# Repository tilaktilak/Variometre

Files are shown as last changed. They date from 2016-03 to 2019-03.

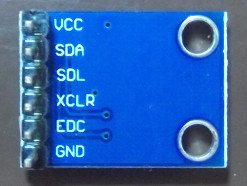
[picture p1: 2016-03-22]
schematic/BMP085.jpg

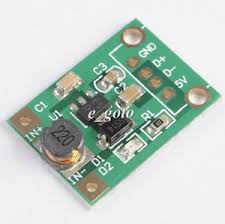
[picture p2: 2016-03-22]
schematic/charger.jpeg

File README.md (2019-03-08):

# Variometre

Here the first Paragliding Computer I've designed : 

(https://postimg.cc/18d83vHh)

This is a variometer / gps / sd logger Atmega328p based project : 

Components :
* a SD card reader connected through SPI to the arduino
* a Nokia LCD screen connected to SPI
* a BMP180 (pressure sensor) connected through I2C
* a GPS Neo-6M receiver in UART.

The PCB is powerd by a 1s battery + a USB battery charger and a boost module to generate 5V.

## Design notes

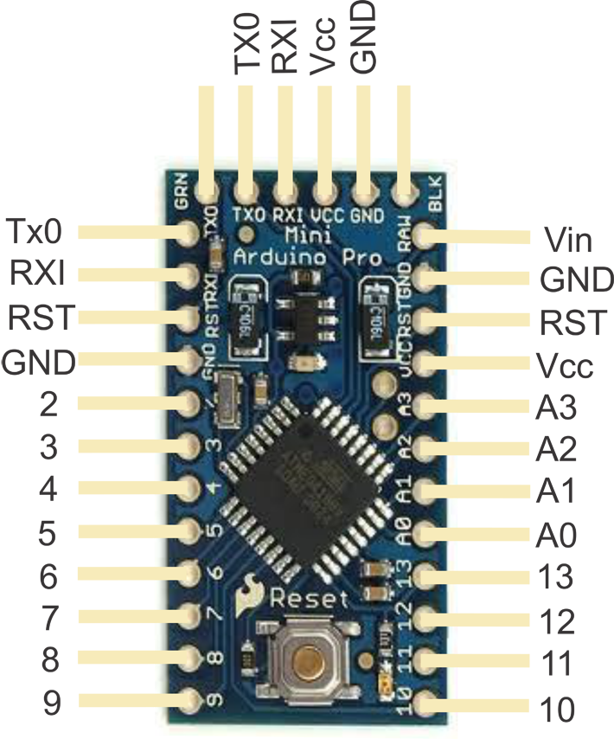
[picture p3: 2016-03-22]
schematic/arduino.png

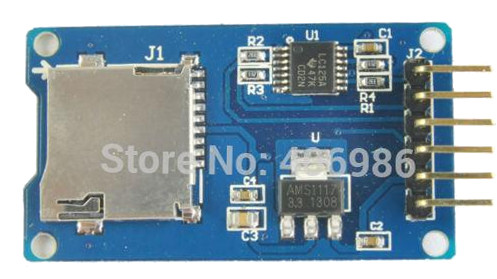
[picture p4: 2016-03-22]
schematic/sd_readet.jpg

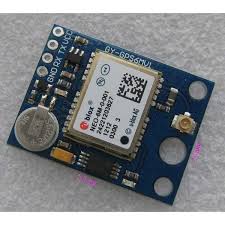
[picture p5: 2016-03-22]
schematic/gps.jpeg

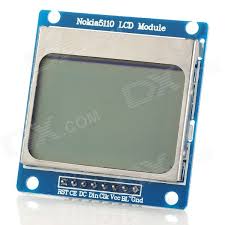
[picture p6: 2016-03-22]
schematic/nokia.jpeg

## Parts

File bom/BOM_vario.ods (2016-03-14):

 |  |  | CAHIER DES CHARGES BOITIER | FEATURES
NOKIA LCD (http://www.ebay.fr/itm/84-48-84x84-LCD-Module-White-backlight-adapter-PCB-for-Nokia-5110-Arduino-MM-/331555581551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) | 1.85 |  | LED CHARGEUR VISIBLE | INTER EXTINCTION SOFTWARE (Ferme fichier SD)
BMP085 (http://www.ebay.fr/itm/BMP180-Replace-BMP085-Digital-Barometric-Pressure-Sensor-Board-Module-NEW-/201539355190) | 1.12 |  | CARTE SD ACCESSIBLE | Clavier : changer les seuils de beep
GPS (http://www.ebay.fr/itm/1p-Ublox-NEO-6M-V2-Flight-GPS-Module-Controleur-De-Vol-pour-Arduino-MWC-IMU-APM2-/161887869415) | 10 |  | INTER ACCESSIBLE MAIS PAS TROP | Clavier : Afficher les stats du vol
SD reader (http://www.ebay.fr/itm/Micro-Storage-Board-Mciro-for-SD-TF-Card-Memory-Shield-Module-SPI-For-Arduino-JK-/262241628919) | 1 |  | USB PRISE ACCESSIBLE | Clavier : Afficher la position courante (en cas de vache !)
DCDC boost (http://www.ebay.fr/itm/221913300409) | 1 |  | BUZZER DEVANT DES TROUS | Mise en veille si pas de chg de position pdt 5mins (Puis réveil)
USB charger (http://www.ebay.fr/itm/5V-Micro-USB-1A-18650-Lithium-Battery-Charging-Board-Charger-Module-New-FR-/111777518426) | 1 |  | ANTENNE GPS NON COUVERTE
1S battery (http://www.ebay.fr/itm/3-7V-1000MAH-1200mAh-25C-Lipo-Battery-RC-Walkera-WKLIPO-5-10-5G4Q3-SYMA-S006-H-/262214846844) | 2.3 |  | CONNECTEUR FLASH ACCESSIBLE
Arduino (http://www.ebay.com/itm/Pro-Mini-atmega328-Board-5V-16M-Arduino-Compatible-Nano-top-/181947224345) | 1.45
INTER ON OFF (http://www.ebay.com/itm/20Pcs-SS12D00G3-2-Position-SPDT-1P2T-3-Pin-PCB-Panel-Vertical-Slide-Switch-FG-/272105930058) | 0.75
SWITCH CLAVIER (http://www.ebay.com/itm/50PCS-6x6x6-mm-Miniature-Micro-Momentary-Tactile-Tact-Touch-Push-Button-Switch-/262136738351) | 0.98
Boitier x 5 (OPTION) |  | 3.73
TOTAL | 21.45

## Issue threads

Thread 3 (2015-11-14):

Mauvaise Ecriture d'Altitude dans IGC (Pressure+GPS)

tilaktilak, 2015-11-14:
Check dtostrf cheat
GPS Alt : Ajouter des zeros lorsque non rempli

tilaktilak, 2015-12-28:
Erreur sur des paquets incomplets : Il faut d'abord remplir un buffer (200 char si possible) et ensuite le sonder pour parser)

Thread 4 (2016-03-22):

Fix GPS lent

tilaktilak, 2016-03-22:
Surement dû au fait que les valeurs sont filtrées si non cohérentes en entrée. Il faut que le voyant indiquant GPS OK soit cohérent avec le début de l'écriture des lignes dans la SD.
Tenter d'améliorer le fix GPS / Gérer le nombre de points par secondes

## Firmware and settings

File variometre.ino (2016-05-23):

#include<stdlib.h>
#include <avr/sleep.h>
#include <SPI.h>
#include <Wire.h>
#include <Adafruit_BMP085.h>
#include <SdFat.h>
#include <PCD8544.h>
#include <EEPROM.h>
#include <TinyGPS++.h>
TinyGPSPlus gps;
#define SIZE_MEM  13

#define     CHANGE_LEVEL    1
#define     ENTER           2
#define     EXIT            3

#define PLOT
//#define NO_TONE

typedef union __attribute__((__packed__)){
    struct __attribute__((__packed__)){
        uint8_t index;
        float   alt_max;
        float   rate_max;
        uint32_t minutes;
    };
    byte raw[sizeof(uint8_t)+2*sizeof(float)+sizeof(uint32_t)];

}memory_t;

memory_t mem;

// Software SPI (slower updates, more flexible pin options):
// pin 7 - Serial clock out (SCLK)
// pin 6 - Serial data out (DIN)
// pin 5 - Data/Command select (D/C)
// pin 4 - LCD chip select (CS)
// pin 3 - LCD reset (RST)

static PCD8544 lcd;

static Adafruit_BMP085 bmp;

SdFat sd;
SdFile dataFile;
char filename[9] = "vari.igc";

// ADD of mem struct in EEPROM
#define STAT_GLOBAL 0x00

void read_EEPROM(byte offset) {
    for (uint8_t i = offset; i < SIZE_MEM; i++){
        mem.raw[i] = EEPROM.read(i);
        Serial.print(mem.raw[i]);
    }
}

void write_EEPROM(byte offset) {
    for (uint8_t i = offset; i < SIZE_MEM;i++){
        EEPROM.write(i,mem.raw[i]);
    }
}

typedef union __attribute__((__packed__)){
    struct __attribute__((__packed__)){
        char b ;
        char time[6];
        char lat[8];
        char lng[9];
        char a;
        char pAlt[5];
        char gAlt[5];
    };
    char raw[35];
}igc_t;

igc_t cur_igc;

char is_gps_valid = 'E';
#if 0
typedef struct{
    const char text[10];
    char value;
    void (* funct)();
}t_item;

typedef struct{
    const char title[15];
    t_item items[2];
    char index;
}t_page;

float level = 0.0;
void set_level(char value){
    level = (float)value;
}

void screen_stat(void){
    lcd.print("stats");
}
t_page page[2] = {"MENU PRINCIPAL",{"[-Level-] ",0x02,set_level},{"[-Stats-] ",0x00,screen_stat},0x00};

#define l_page 0
#define l_item 1
#define l_value 2
void do_menu(){
    t_page cur_page = page[0]; // Page to screen
    char button = 0x00;
    uint8_t i = 0;
    char level; // 0, 1 or 2
    bool exit_menu = false;
    while(!exit_menu){
        //display(page,level); // page with highlight level
        switch(0){//Read_button()){
            case CHANGE_LEVEL :
                if(level < 0X02) level ++;
                else level = 0x00;
                break;
            case ENTER :
                if(level == l_page){cur_page=page[++i];}
                if(level == l_item){cur_page = index++;}
                if(level == l_value){cur_page.item[cur_page.index].funct();}
                break;
            case EXIT :
                exit_menu = true;
                break;
            case Default:
                break;
        }
        }
    }
#endif
    static float batt;
    void setup() {
        memset(&cur_igc,'0',sizeof(cur_igc));
        cur_igc.a = 'A';
        cur_igc.b = 'B';

        // Fetch last file index
        mem.index = 0;
        mem.alt_max = 0.0f;
        mem.rate_max = 0.0f;
        mem.minutes = 0;
        // Fetch stats in memory
        Serial.begin(9600);

        read_EEPROM(STAT_GLOBAL);
        Serial.println(mem.alt_max);
        // Prepare filename with current index
        filename[1] = (mem.index / 100) % 10 + '0';
        filename[2] = (mem.index / 10) % 10 + '0';
        filename[3] = (mem.index) % 10 + '0';
        mem.index ++;

        lcd.begin(84, 48);
        lcd.clear();

        pinMode(A0, OUTPUT);// Backlight
        pinMode(2, OUTPUT);// Tone
        pinMode(A1, OUTPUT);// Voltage
        digitalWrite(A0,0);


        if (!sd.begin(10, SPI_FULL_SPEED)) {
            sd.initErrorHalt();
        }
        if (!bmp.begin(3)) {
            while (1) {}
        }
        if(!dataFile.open(filename,O_RDWR | O_CREAT | O_TRUNC)){
            lcd.print(F("FILE ERR"));
            lcd.setCursor(0, 5);
            lcd.print(filename);
            while (1);
        }
        
        dataFile.print(F("AXXX Tilak_Logger\r\
HFDTE020911\r\
HFFXA035\r\
HFPLTPILOTINCHARGE: Pierre-Louis TILAK\r\
HFCM2CREW2: not recorded\r\
HFGTYGLIDERTYPE:Advance Alpha5 23\r\
HFGIDGLIDERID:0\r\
HFDTM100GPSDATUM: WGS-1984\r\
HFRFWFIRMWAREVERSION: 1.2\r\
HFRHWHARDWAREVERSION: 2016\r\
HFFTYFRTYPE: Ardiuno Tilak Logger\r\
HFGPSGPS:Ublox Neo6m\r\
HFPRSPRESSALTSENSOR: BMP180\r\
HFCIDCOMPETITIONID:\r\
HFCCLCOMPETITIONCLASS:\r"));
        // Flush data
        dataFile.sync();
        dataFile.getWriteError();

        // Initialize battery voltage measure
        batt += (float)analogRead(A1) * (5.0/1023.0) - 0.24;
    }

    uint8_t count;
    bool tone_done = false;
    static int start_beep;
    static int duration, old_duration;
    static int timer;
    static bool inits = true;
    static bool in_flight = true;
    uint8_t i_t = 0;

    void loop() {

        static unsigned long sec = 0;
        static uint8_t old_minu = 0;
        static uint8_t minu = 0;
        static uint8_t hour = 23;
        static unsigned long usec = 0;
        static unsigned long old_usec = 0;
        static float alt, old_alt, smooth;
        static float raw_deriv,derivative;
        static int16_t freq;
        static uint8_t count_lcd = 0;
        static uint8_t count_sd = 0;
        static uint8_t count_gps = 0;
        static float avg_batt;
        static uint8_t avg_batt_count = 0;
        static float ground_speed = 0.0f;

        char heure[8];
#if 0
        if(digitalRead(ENTER)==HIGH){
            delay(1);
            while(digitalRead(ENTER)==HIGH);
            do_menu();
        }
#endif
        // Update Time
        usec = millis();
        sec = usec / 1000;
        minu = sec / 60;
        hour = minu / 60;

        alt = bmp.readAltitude();
        if (inits) {
            smooth = alt;
            old_alt = alt;
            old_usec = usec;
            inits = false;
        }

        // Process Pressure
        smooth = 0.97 * smooth + 0.03* alt;

        // Process Derivative
        if ((old_usec - usec) >= 100) {
            raw_deriv = ((smooth    - old_alt) * 1000) /(usec - old_usec);
            old_usec = usec;
            old_alt = smooth;
        }
        derivative = 0.9 * derivative + 0.1 * raw_deriv;

        //if(abs(derivative) > 1.0){in_flight = true;}
#ifdef PLOT
        dataFile.print(usec);
        dataFile.print(",");
        dataFile.print(smooth);
        dataFile.print(",");
        dataFile.print(derivative);
        dataFile.print(",");
        dataFile.print(raw_deriv);
        dataFile.print("\n");
        if(in_flight){
            // Update stat
            if(mem.rate_max < derivative) mem.rate_max = derivative;
            // Update stat
            if(mem.alt_max < alt) mem.alt_max = alt;
        }
        // Flush data
        dataFile.sync();
        dataFile.getWriteError();
#endif

        // TONE
#define RISING_LEVEL 0.23
#define FALLING_LEVEL 0.4
#define PERIOD_MAX 400
        if (derivative >= RISING_LEVEL) {
            //duration = (int) 50 + 70 / abs(derivative);
            duration = (int) ((-derivative)*70 + 400);
        }
        else if(derivative <= -FALLING_LEVEL){
            //duration = (int) 100 + 200 / abs(derivative);
            duration = (int) ((derivative)*35 +  400);
        }
        else {
            duration = 0;
        }
        duration = constrain(duration, 0, 400);
        freq = (int) (640 + 200 * derivative);
        if(derivative<0)freq-=250;
        freq = constrain(freq, 40, 4000);

        if (!tone_done) {
            if (duration != 0)
#ifndef NO_TONE
                tone(2, freq, duration);
#endif
            tone_done = true;
            start_beep = millis();
            old_duration = duration;
        }
        timer = start_beep + 2 * old_duration - millis();
        if (timer < 10) {
            tone_done = false;
        }
        switch (count) {
            case 1 : // Print data on screen
                count_lcd ++;
                if (count_lcd == 5) {


                    lcd.setCursor(0, 0);

                    if ((hour % 24) < 10) lcd.print("0");
                    lcd.print(hour % 24);
                    lcd.print(":");
                    if ((minu % 60) < 10) lcd.print("0");
                    lcd.print(minu % 60);
                    lcd.print(":");
                    if ((sec % 60) < 10) lcd.print("0");
                    lcd.print(sec % 60);
                    lcd.setCursor(55, 0);

                    avg_batt += (float)analogRead(A1) * (5.0/1023.0) - 0.24;
                    avg_batt_count ++;
                    if(avg_batt_count >= 30){
                        avg_batt /= avg_batt_count;

                        batt = avg_batt;

                        avg_batt = 0;
                        avg_batt_count = 0;

                    }
                    if(batt >= 4.00) lcd.print("~~~}");
                    else if(batt >= 3.80) lcd.print(" ~~}");
                    else if(batt >= 3.70) lcd.print("  ~}");
                    else if(batt >= 3.40) lcd.print("   }");
                    else if(batt >= 1.00){
                        // Got into sleep mode
                        lcd.print(batt);
                        lcd.setCursor(0,3);
                        lcd.print(" BATT LOW !");
                        lcd.setCursor(0,5);
                        lcd.print(" SHUT DOWN !");
                        while(1){
                            tone(2, 500, 1000);
                            delay(3000);
                        }
                        //dataFile.close();
                        lcd.clear();
                        set_sleep_mode(SLEEP_MODE_PWR_DOWN);
                        cli();
                        sleep_enable();
                        sleep_bod_disable();
                        sei();
                        sleep_mode();
                    }
                    else{
                        lcd.setCursor(0,2);
                        lcd.print("Device");
                        lcd.setCursor(0,3);
                        lcd.print("Connected");
                        while(1);
                    }
                    lcd.setCursor(79, 0);

                    lcd.print((gps.location.isValid())?"{":"X");

                    lcd.setCursor(0, 1);
                    lcd.set_size(0x02);
                    lcd.print(ground_speed);

                    lcd.set_size(0x01);
                    lcd.print("km/h  ");
                    lcd.setCursor(0,3);
                    lcd.print(smooth);
                    lcd.print(" m    ");

                    lcd.set_size(0x02);
                    lcd.setCursor(0,4); 
                    if(derivative>0.0){lcd.print("+");}
                    lcd.print(derivative);
                    lcd.set_size(0x01);
                    lcd.print("m/s");
                    count_lcd = 0;
                }
                break;
            case 2: // Read GPS & Write data to SD Card
                //count_sd ++;
                if (in_flight  && gps.location.isValid()) {
                    if((strlen(gps.c_lon)==8)&&
                            (strlen(gps.c_lat)==7)&&
                            (gps.dir_lat=='N'||gps.dir_lat=='S')&&
                            (gps.dir_lon=='W'||gps.dir_lon=='E')&&
                            !(gps.time.hour()==0&&gps.time.minute()==0&&gps.time.second()==0)){
                        ground_speed = gps.speed.kmph();

                        dataFile.print("B");
                        if (gps.time.hour() < 10) dataFile.print(F("0"));
                        dataFile.print(gps.time.hour());

                        if (gps.time.minute() < 10) dataFile.print(F("0"));
                        dataFile.print(gps.time.minute());
                        if (gps.time.second() < 10) dataFile.print(F("0"));
                        dataFile.print(gps.time.second());

                        dataFile.print(gps.c_lat);
                        dataFile.print(gps.dir_lat);
                        dataFile.print(gps.c_lon);
                        dataFile.print(gps.dir_lon);
                        dataFile.print("A");
                        if(smooth<10)dataFile.print("0000");
                        else if(smooth<100) dataFile.print("000");
                        else if(smooth<1000) dataFile.print("00");
                        else if(smooth<10000) dataFile.print("0");
                        dataFile.print(smooth,0);

                        if(smooth<10)dataFile.print("0000");
                        else if(smooth<100) dataFile.print("000");
                        else if(smooth<1000) dataFile.print("00");
                        else if(smooth<10000) dataFile.print("0");
                        dataFile.println(gps.altitude.meters(),0);
                        // Flush data
                        dataFile.sync();
                        dataFile.getWriteError();
                    }
                    count_sd = 0;
                }
                break;
            case 3 :
                if(in_flight){
                    if(minu >= old_minu+10){
                        mem.minutes+= (minu-old_minu);
                        old_minu = minu;
                    }
                    write_EEPROM(STAT_GLOBAL);
                }
                count = 0;
                break;
           default:
                break;
        }
        count++;
    }
    
void serialEvent(){
    while (Serial.available() > 0) {
        gps.encode(Serial.read());
    }
}

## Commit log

2015-10-11 Premier Commit, code example threadé
2015-10-20 version avec beeper,SD et écran - pas de menu ni GPS
2015-10-25 Ralenti du LCD et de la SD
2015-10-25 Version avec GPS + Format correct IGC + MaJ du nom de fichier 0-255
    [variometre.ino]
2015-10-26 Version buggué sur l'affichage - TODO : Essayer d'agrandir/modifier l'affichage, Calibrer l'altitude avec un zero fait grace à la valeur du GPS. Limiter en amplitude des valeurs successices de la dér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
    [variometre.ino]
2015-11-05 Début de la fonction de parsing des NMEA
    A ajouter : CF IGC050 il faut parser du GGA et
    pas du RMC. Par contre l'algo RMC a été
    testé en statique
2015-11-14 Test du parsing NMEA OK, Correction de la RaZ close #1
    [variometre.ino]
2015-11-22 Correction Stats en EEPROM close issue #2
    L'EEPROM n'était pas initialisée avec la structure mem
    [variometre.ino]
2015-12-07 Modifs Processing
    Corrections de la latence
    Modif In_flight removed
    [variometre.ino]
2015-12-10 Debut de l'intégration du menu
    Attention ne compile pas !
2015-12-21 Modifications (non fix) du GPS
    [variometre.ino]
2016-01-06 Increase parser severity
    Add else case : retry.
    Modify altitude parsing (with scalable size)
2016-01-09 Not Working : Modif GPS
    [variometre.ino]
2016-02-01 Réajout de la lib GPS TinyGPS++
    Problème sur les premieres lignes sans altitude
    Problème sur l'unité des Lon/Lat (deg/min ?)
2016-03-12 Fonctionnement OK, bugs il manque long de temps en temps
    [variometre.ino]
2016-03-13 Hot Fix GPS
    Pas de ligne si valeur abérente pour lon/lat
    [variometre.ino]
2016-03-13 Calibration mesure Batterie
    Conso en veille : 170mAh !
2016-03-14 Hot Fix GPS 2 : Size lon/lat faux
    Ajout de la BOM
    [BOM_vario.ods]
2016-03-14 Modifs BOM
    [BOM_vario.ods]
2016-03-21 modification de l'afficher (grand)
    [BOM_vario.ods]
2016-03-21 Test de la lib SDFat pour récupérer 10kb
2016-03-21 Correction : Creation fichier ecrasante
    [variometre.ino]
2016-03-22 Ajout des schematic/bom
    [BOM_vario.ods, schematic.fzz, schematic.kicad_pcb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]
2016-05-19 Modifications seuils beep : en -x au lieu de 1/x
    Commit precedant corrige legerement les seuils,
    Ajoute le Vx (non fonctionnel)
    [variometre.ino]
2016-05-23 Ajout de l'USART en interruption
